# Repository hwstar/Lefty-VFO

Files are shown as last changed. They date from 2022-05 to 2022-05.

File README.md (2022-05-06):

# Lefty-VFO
Lefty Quad output VFO Motherboard

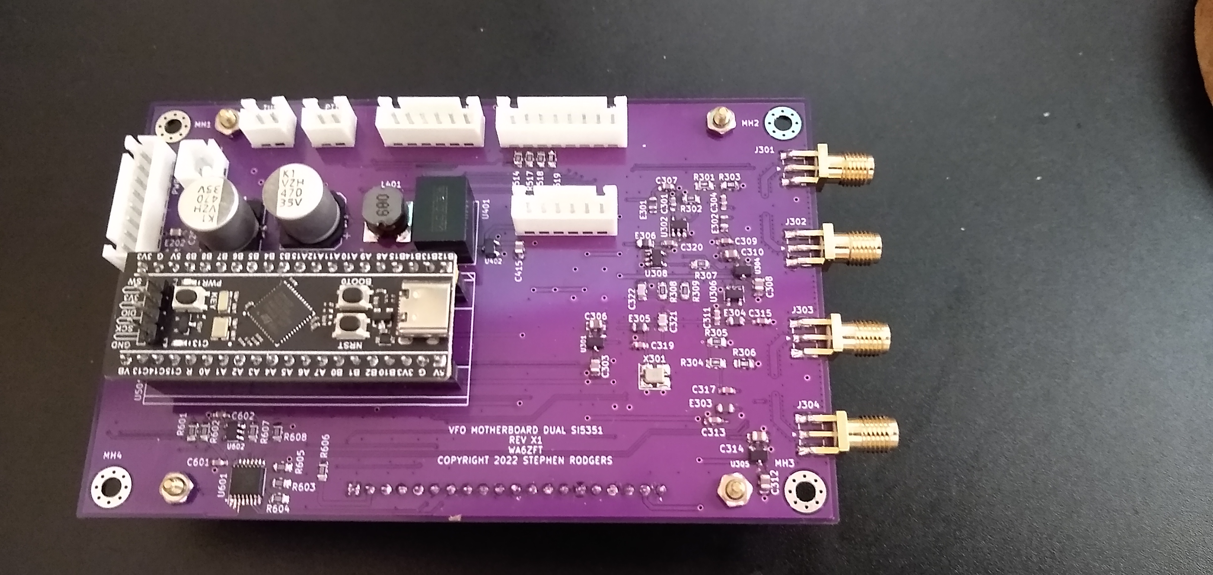
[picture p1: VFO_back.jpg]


This is a 4 output VFO module for the lefty transceiver.

It uses 2 SI5351/MS5351 clock generator chips. 

There is a 4 channel PCA9546 I2C multiplexer on the board which is used to switch between the two SI5351's since they have a fixed device address.

Each SI5351 is driven from a common 26 MHz TCXO source using 74LVC1G04's as a buffer.

The SI5351's have dedicated ME6211 3.3V regulators to reduce cross coupling of spurs on the 3.3v power rails.

The VFO board used a Weact "Black Pill" STM32 MPU module. This module has 512kB of flash and 128kB of ram.

The display mounts on the front of the board using a 20 pin female socket header. The display used is a 3.3V 12864 monochrome display with SPI bus capability.

The vfo board is powered from 9-15V and uses a 12V to 5V switching power supply module with input PI filter to reduce the noise generated from the switcher module.

There is one 8 pin JST XH connector supplies 12V power and provides access to the I2C bus coming from one of the PCA9546 outputs.

The vfo board supports an optional 4x4 keypad, and an optical encoder.

There are 2 pin connector for the fan output. 

There are 2 pin connectors for the ptt, tune, and s-meter inputs.

There is a 6 pin connector for the UART in the Black pill.

There is an I2C EEPROM on the board to facilitate storing VFO configuration settings

The PCB design was done with KiCAD 6.0. The BOM files are in .csv format and are included in the top level directory. There is a combined BOM, and separate top and bottom SMT BOM's.

The firmware for the VFO is in a separate project located [here] (https://github.com/hwstar/FW_VFO_STM32_BLACK_PILL_ST7920) 

The gerber files are in the directory VFO_Rev_X2_Gerbers.

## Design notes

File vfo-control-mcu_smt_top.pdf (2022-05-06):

vfo-control-mcu_smt_top

Page 1

Item Part Number Qty Reference(s) | Title/Description | Value on Schematic | Manufacturer | Manufacturer Part Number
1 800270-477 | 2 C201,C202 | CAP,ALUM,ELECT,GP,470UF,25V,SMD,CS=10MM | 470u | Open Market | N/A
2 800238-104 | 1 C206 | CAP,0805,0.1u,50V,X7R | 0.1u | Open Market | N/A
3 800000-104 | 12 C301,C304,C307,C309,C311,C313,C315,C317,C319,C320,C601,C602CAP,0603,0.1u,25V,X7R | 0.1u | Open Market | N/A
4 800238-105 | 6 C303,C306,C308,C310,C312,C314 | CAP,0805,1u,50V,X7R | 1u | Open Market | N/A
5 800238-103 | 2 C321,C322 | CAP,0805,0.01u,50V,X7R | 0.01u | Open Market | N/A
6 800003-106 | 1 C412 | CAP,0805,10u,25V,X5R | 10u | Open Market | N/A
7 800003-225 | 1 C415 | CAP,0805,2.2u,25V,X5R | 2.2u | Open Market | N/A
8 800040-600 | 7 E202,E301-E306 | FERRITE,CHIP,0603,600 OHM,500MA | FB0805 | TDK | MMZ1608S601A
9 800233-101 | 4 J301-J304 | CONN,SOC,SMA,LAUNCH,0.062 PCB | CONN_SMA_LAUNCH | Kinghelm | KH-SMA-KE8-G
10 800114-102 | 3 J402,J403,J405 | CONN,HDR,SHROUDED,2 CKT,5MM,XH SERIES | CONN2 | JST | B2B-XH-A
11 800114-108 | 2 J404,J506 | CONN,HDR,SHROUDED,8 CKT,5MM,XH SERIES | CONN8 | JST | B8B-XH-A
12 800114-106 | 2 J501,J502 | CONN,HDR,SHROUDED,6 CKT,5MM,XH SERIES | CONN6 | JST | B6B-XH-A
13 800281-101 | 1 L401 | IND,68UH,990MA,280MILLIOHM,SMD | 68uH | Recom | RLS-686
14 800235-680 | 2 R301,R304 | RES,0805,68,1% | | 68 Open Market | N/A
15 800235-101 | 4 R302,R303,R305,R306 | RES,0805,100,1% | | 100 Open Market | N/A
16 800235-300 | 1 R307 | RES,0805,30,1% | | 33 Open Market | N/A
17 800235-474 | 2 R308,R309 | RES,0805,470K,1% | 470K | Open Market | N/A
18 800235-330 | 4 R514,R517-R519 | RES,0805,33,1% | | 33 Open Market | N/A
19 800235-103 | 8 R601-R608 | RES,0805,10K,1% | 10K | Open Market | N/A
20 800187-101 | 4 U301,U304,U305,U402 | IC,VREG,LDO,500MA,3.3V,SOT23 | ME6211A33M3G-N | Nanjing Micro One Elec ME6211A33M3B-N
21 800289-101 | 3 U302,U306,U308 | IC,INVERTER,LVC04,SINGLE,SOT-23 | 74LVC1G04 | Texas Instruments | SN74LVC1G04DBVT
22 800201-500 | 1 U401 | MODULE,REGULATOR,SWITCHING,1A,5.0V | R-78E5.0-1.0 | Recom | R-78E5.0-1.0
23 800280-101 | 1 U501 | MODULE,STM32F411CEU6,BLACK PILL,40 PIN DIP | BLACK_PILL_WE_ACT_STM32F411CEU6 Open Market | N/A
24 800290-101 | 1 U601 | IC,SWITCH,I2C,4 CHANNEL,TSSOP16 | PCA9546APW | NEXPERIA | PCA9546APW,112
25 800284-101 | 1 U602 | IC,EEPROM,64KBIT,I2C,1.6-5.5V,SOT23-5 | 24CW640 | Microchip | 24CW640T-I/OT
26 800291-256 | 1 X301 | OSC,TCXO,26MHZ,0.5PPM,CLIPPED SINE, 3.3V,SMT,3225 OSC-ABRACON-ATX-11 | Abracon | ATX-11-F-26.000MHz-F05-T
27 XXXXXX-XXX | 0 | DNI | DNI | DNI | DNI

vfo-control-mcu_smt_top

Page 2

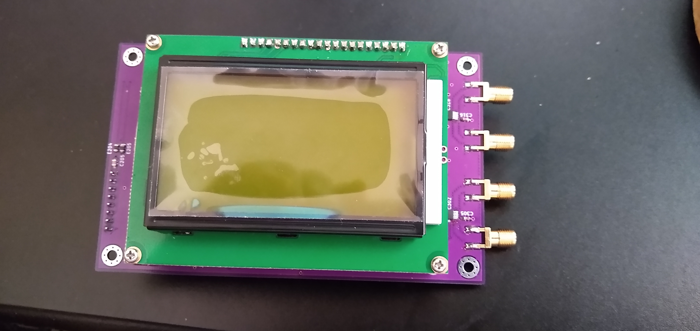
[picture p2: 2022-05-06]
VFO_front.jpg

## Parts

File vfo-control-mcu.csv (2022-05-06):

Item | Part Number | Qty | Reference(s) | Title/Description | Value on Schematic | Manufacturer | Manufacturer Part Number
1 | 800270-477 | 2 | C201,C203 | CAP,ALUM,ELECT,GP,470UF,25V,SMD,CS=10MM | 470u | Open Market | N/A
2 | 800239-102 | 2 | C202,C204 | CAP,0805,C0G/NPO,1000PF,50V | 1000p | Open Market | N/A
3 | 800238-104 | 7 | C205,C206,C405,C501-C504 | CAP,0805,0.1u,50V,X7R | 0.1u | Open Market | N/A
4 | 800063-104 | 16 | C301,C302,C304,C305,C307,C309,C311,C313,C315-C320,C601,C602 | CAP,0603,0.1u,50V,X7R | 0.1u | Open Market | N/A
5 | 800238-105 | 6 | C303,C306,C308,C310,C312,C314 | CAP,0805,1u,50V,X7R | 1u | Open Market | N/A
6 | 800238-103 | 2 | C321,C322 | CAP,0805,0.01u,50V,X7R | 0.01u | Open Market | N/A
7 | 800003-106 | 2 | C401,C402 | CAP,0805,10u,25V,X5R | 10u | Open Market | N/A
8 | 800003-225 | 2 | C403,C404 | CAP,0805,2.2u,25V,X5R | 2.2u | Open Market | N/A
9 | 800109-101 | 1 | CR201 | DIODE, RECT,SHOTTKY,1A,50V,SMA | S1A | Fairchild Semiconductor | ES1A
10 | 800245-601 | 11 | E201-E205,E301-E306 | FERRITE,CHIP,0805,600 ohm,100MHz,500mA | FB0805 | Sunlord | GZ2012U601TF
11 | 800283-020 | 1 | J201 | CONN,SOC,1X20,VERT,0.1 IN PITCH | Conn_01x20 | Open Market | N/A
12 | 800114-102 | 4 | J202-J204,J503 | CONN,HDR,SHROUDED,2 CKT,5MM,XH SERIES | CONN2 | JST | B2B-XH-A
13 | 800114-108 | 2 | J205,J501 | CONN,HDR,SHROUDED,8 CKT,5MM,XH SERIES | CONN8 | JST | B8B-XH-A
14 | 800233-101 | 4 | J301-J304 | CONN,SOC,SMA,LAUNCH,0.062 PCB | CONN_SMA_LAUNCH | Kinghelm | KH-SMA-KE8-G
15 | 800114-106 | 2 | J502,J504 | CONN,HDR,SHROUDED,6 CKT,5MM,XH SERIES | CONN6 | JST | B6B-XH-A
16 | 800281-101 | 1 | L401 | IND,68UH,990MA,280MILLIOHM,SMD | 68uH | Recom | RLS-686
17 | 800123-101 | 2 | Q201,Q202 | XSTR,MOSFET,N-CH,4.0A,30V,SOT-23 | SI2306 | Diodes Inc. | DMN3112S-7
17 |  |  |  |  |  | Vishay | SI2306BDS-T1-E3
18 | 800248-240 | 2 | R201,R202 | RES,2512,24 OHM, 1%,1W | 24 | Open Market | N/A
19 | 800235-680 | 2 | R301,R304 | RES,0805,68,1% | 68 | Open Market | N/A
20 | 800235-101 | 2 | R302,R305 | RES,0805,100,1% | 100 | Open Market | N/A
21 | 800235-330 | 8 | R303,R306,R307,R513,R516-R519 | RES,0805,33,1% | 33 | Open Market | N/A
22 | 800235-474 | 2 | R308,R309 | RES,0805,470K,1% | 470K | Open Market | N/A
23 | 800235-123 | 2 | R401,R522 | RES,0805,12K,1% | 12K | Open Market | N/A
24 | 800235-302 | 1 | R402 | RES,0805,3K,1% | 3K | Open Market | N/A
25 | 800235-332 | 10 | R501-R506,R523-R526 | RES,0805,3.3K,1% | 3.3K | Open Market | N/A
26 | 800235-221 | 4 | R507-R510 | RES,0805,220,1% | 220 | Open Market | N/A
27 | 800235-102 | 4 | R511,R512,R514,R515 | RES,0805,1.0K,1% | 1K | Open Market | N/A
28 | 800235-471 | 2 | R520,R521 | RES,0805,470,1% | 470 | Open Market | N/A
29 | 800235-103 | 8 | R601-R608 | RES,0805,10K,1% | 10K | Open Market | N/A
30 | 800187-101 | 4 | U301,U304,U305,U402 | IC,VREG,LDO,500MA,3.3V,SOT23 | ME6211A33M3G-N | Nanjing Micro One Elec | ME6211A33M3B-N
31 | 800289-101 | 3 | U302,U306,U308 | IC,INVERTER,LVC04,SINGLE,SOT-23 | 74LVC1G04 | Texas Instruments | SN74LVC1G04DBVT
32 | 800288-101 | 2 | U303,U307 | IC, PROG CLOCK GEN,3 OUTPUT, I2C,MSOP10 | Si5351 | RUIMENG TECHNOLOGY | MS5351M
32 |  |  |  |  |  | Skyworks | SI5351A-B-GTR
33 | 800201-500 | 1 | U401 | MODULE,REGULATOR,SWITCHING,1A,5.0V | R-78E5.0-1.0 | Recom | R-78E5.0-1.0
34 | 800280-101 | 1 | U501 | MODULE,STM32F411CEU6,BLACK PILL,40 PIN DIP | BLACK_PILL_WE_ACT_STM32F411CEU6 | Open Market | N/A
35 | 800199-101 | 2 | U502,U503 | IC,SCHMITT TRIGGER,INVERTING,2.0-5.5V,SOT23-5 | 74LVC1G14 | Texas Instruments | SN74LVC1G14DBVR
36 | 800290-101 | 1 | U601 | IC,SWITCH,I2C,4 CHANNEL,TSSOP16 | PCA9546APW | NEXPERIA | PCA9546APW,112
37 | 800284-101 | 1 | U602 | IC,EEPROM,64KBIT,I2C,1.6-5.5V,SOT23-5 | 24CW640 | Microchip | 24CW640T-I/OT
38 | 800291-256 | 1 | X301 | OSC,TCXO,26MHZ,0.5PPM,CLIPPED SINE, 3.3V,SMT,3225 | OSC-ABRACON-ATX-11 | Abracon | ATX-11-F-26.000MHz-F05-T
39 | XXXXXX-XXX | 0 |  | DNI | DNI | DNI | DNI

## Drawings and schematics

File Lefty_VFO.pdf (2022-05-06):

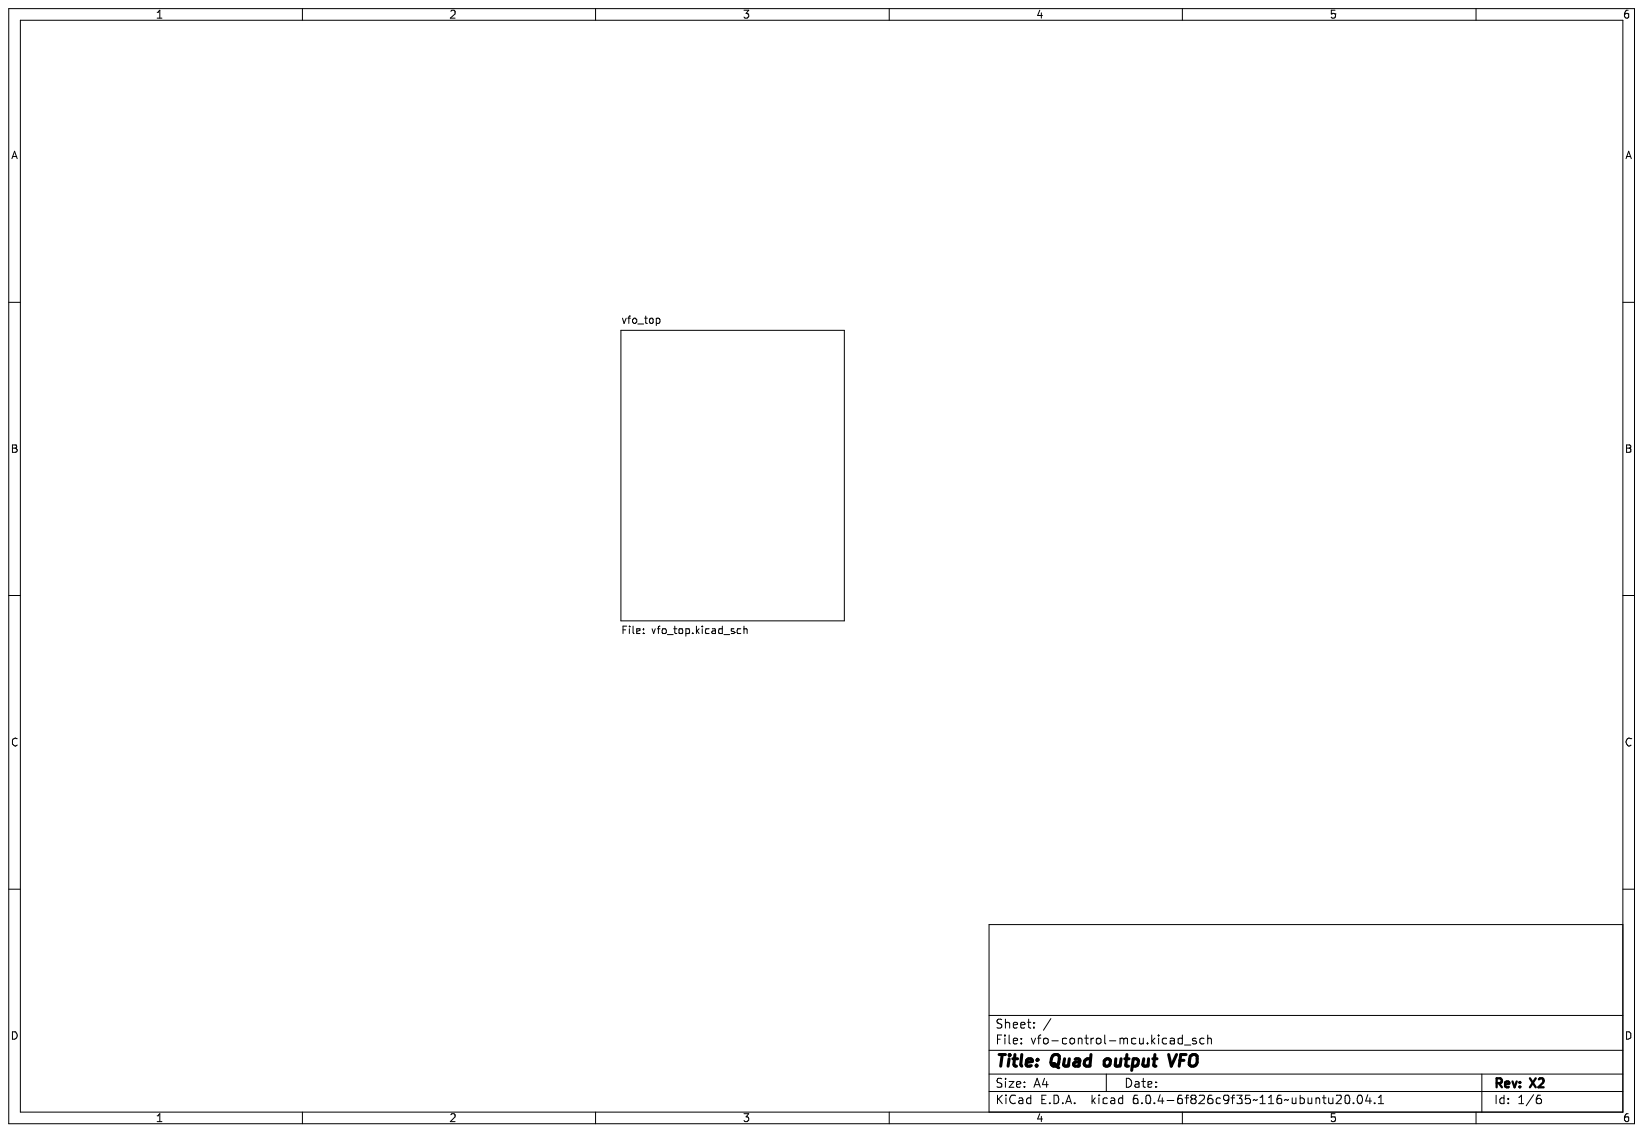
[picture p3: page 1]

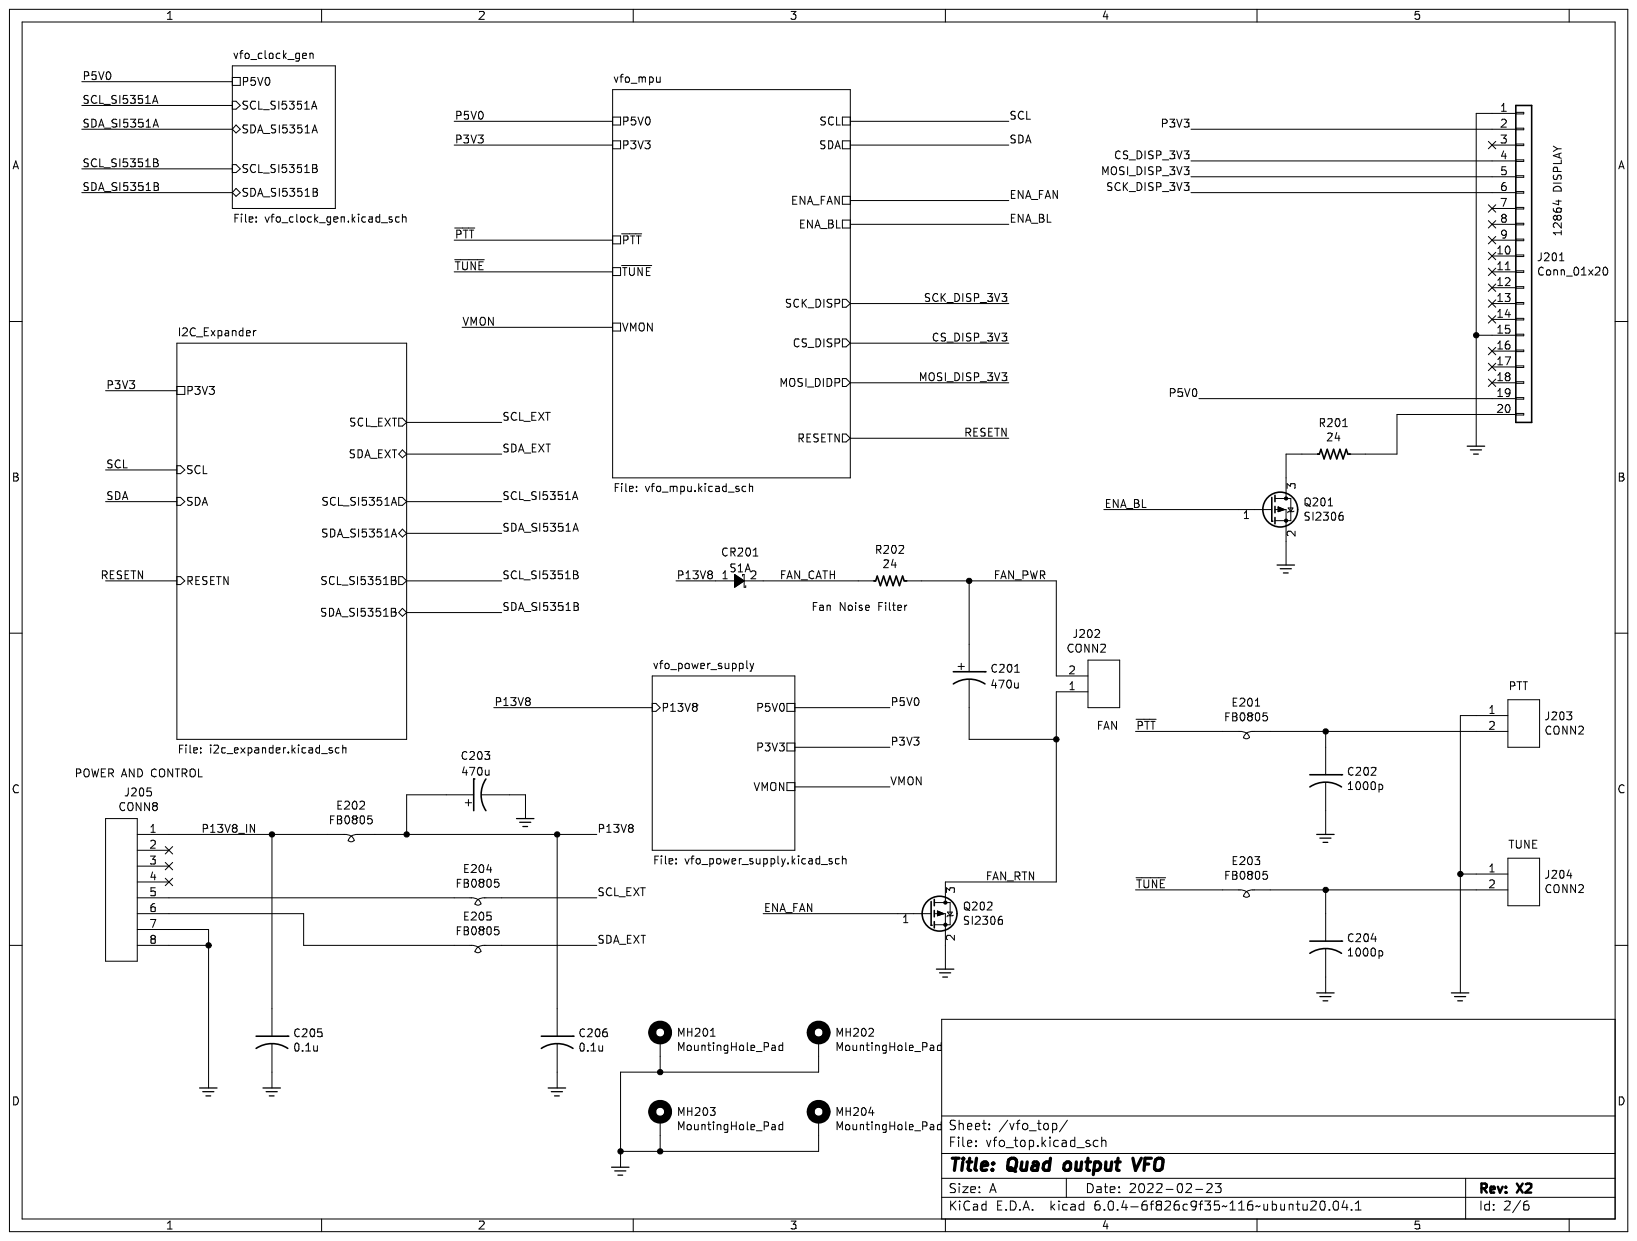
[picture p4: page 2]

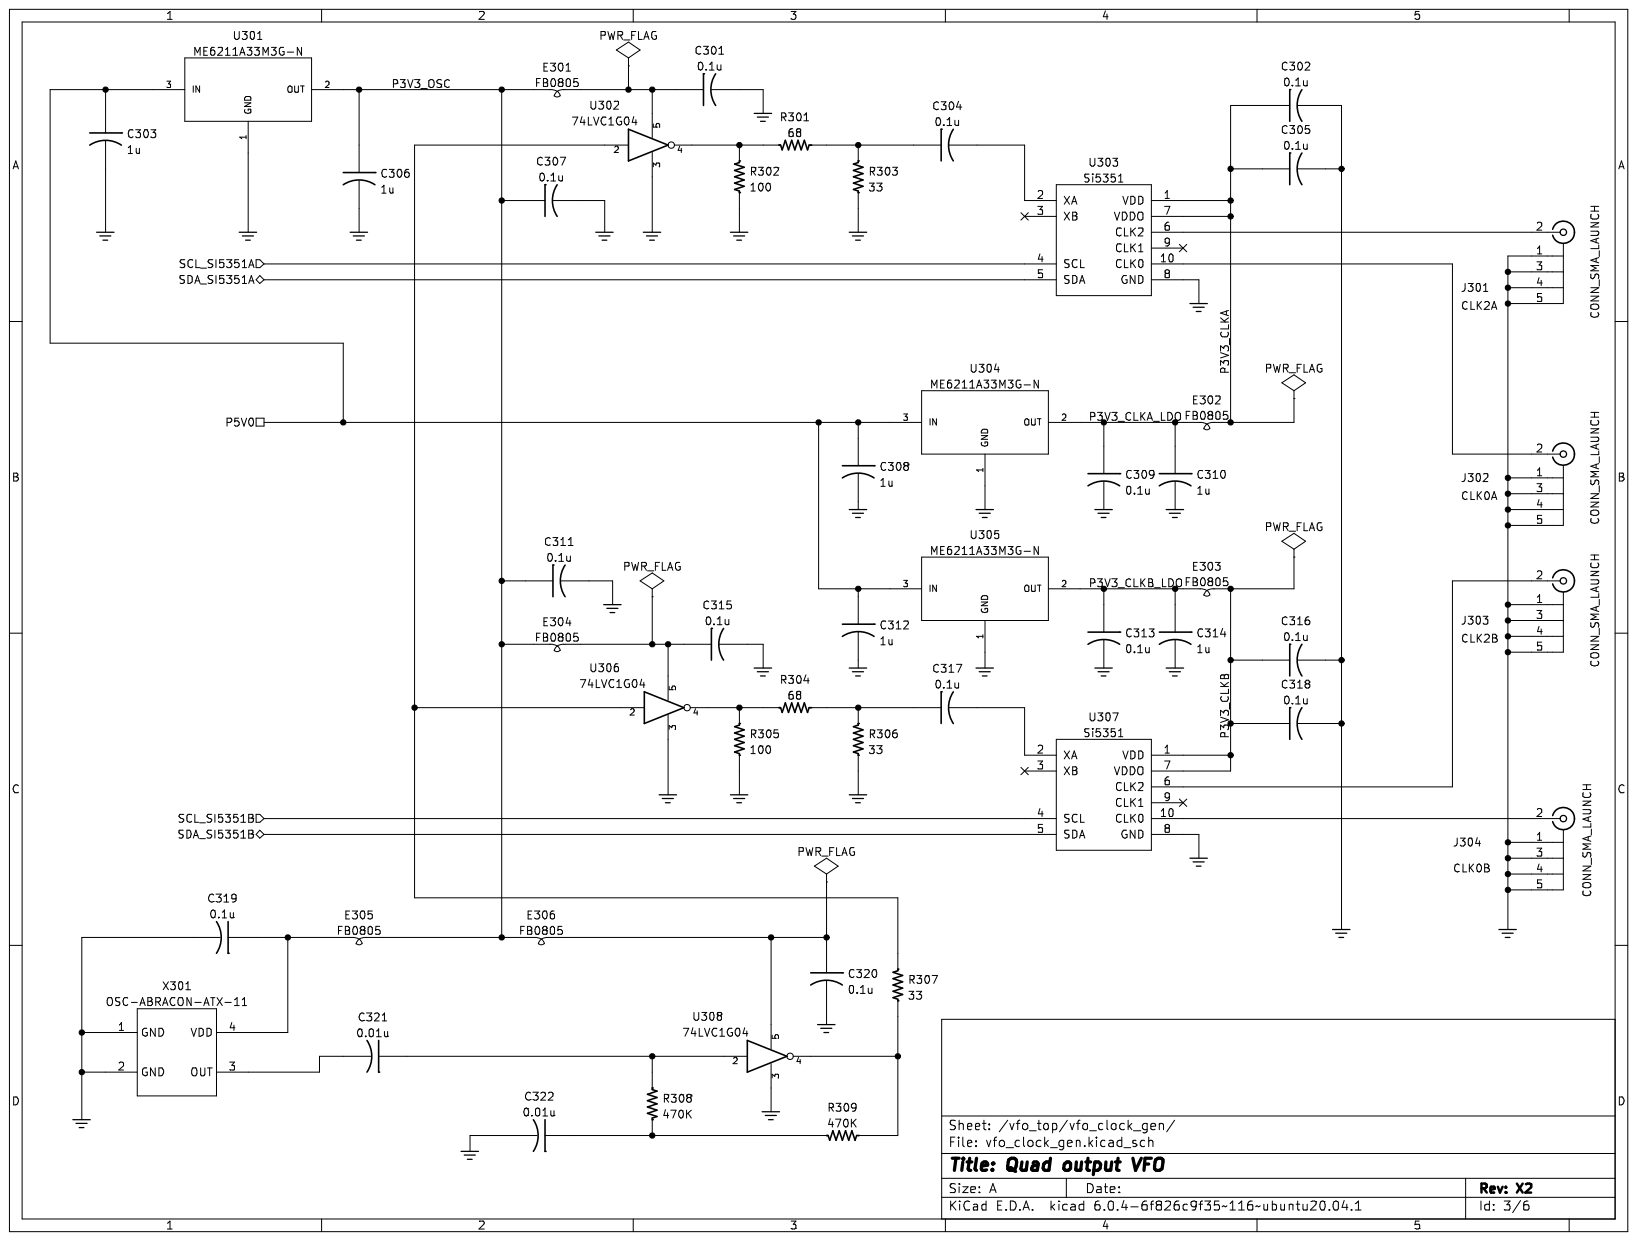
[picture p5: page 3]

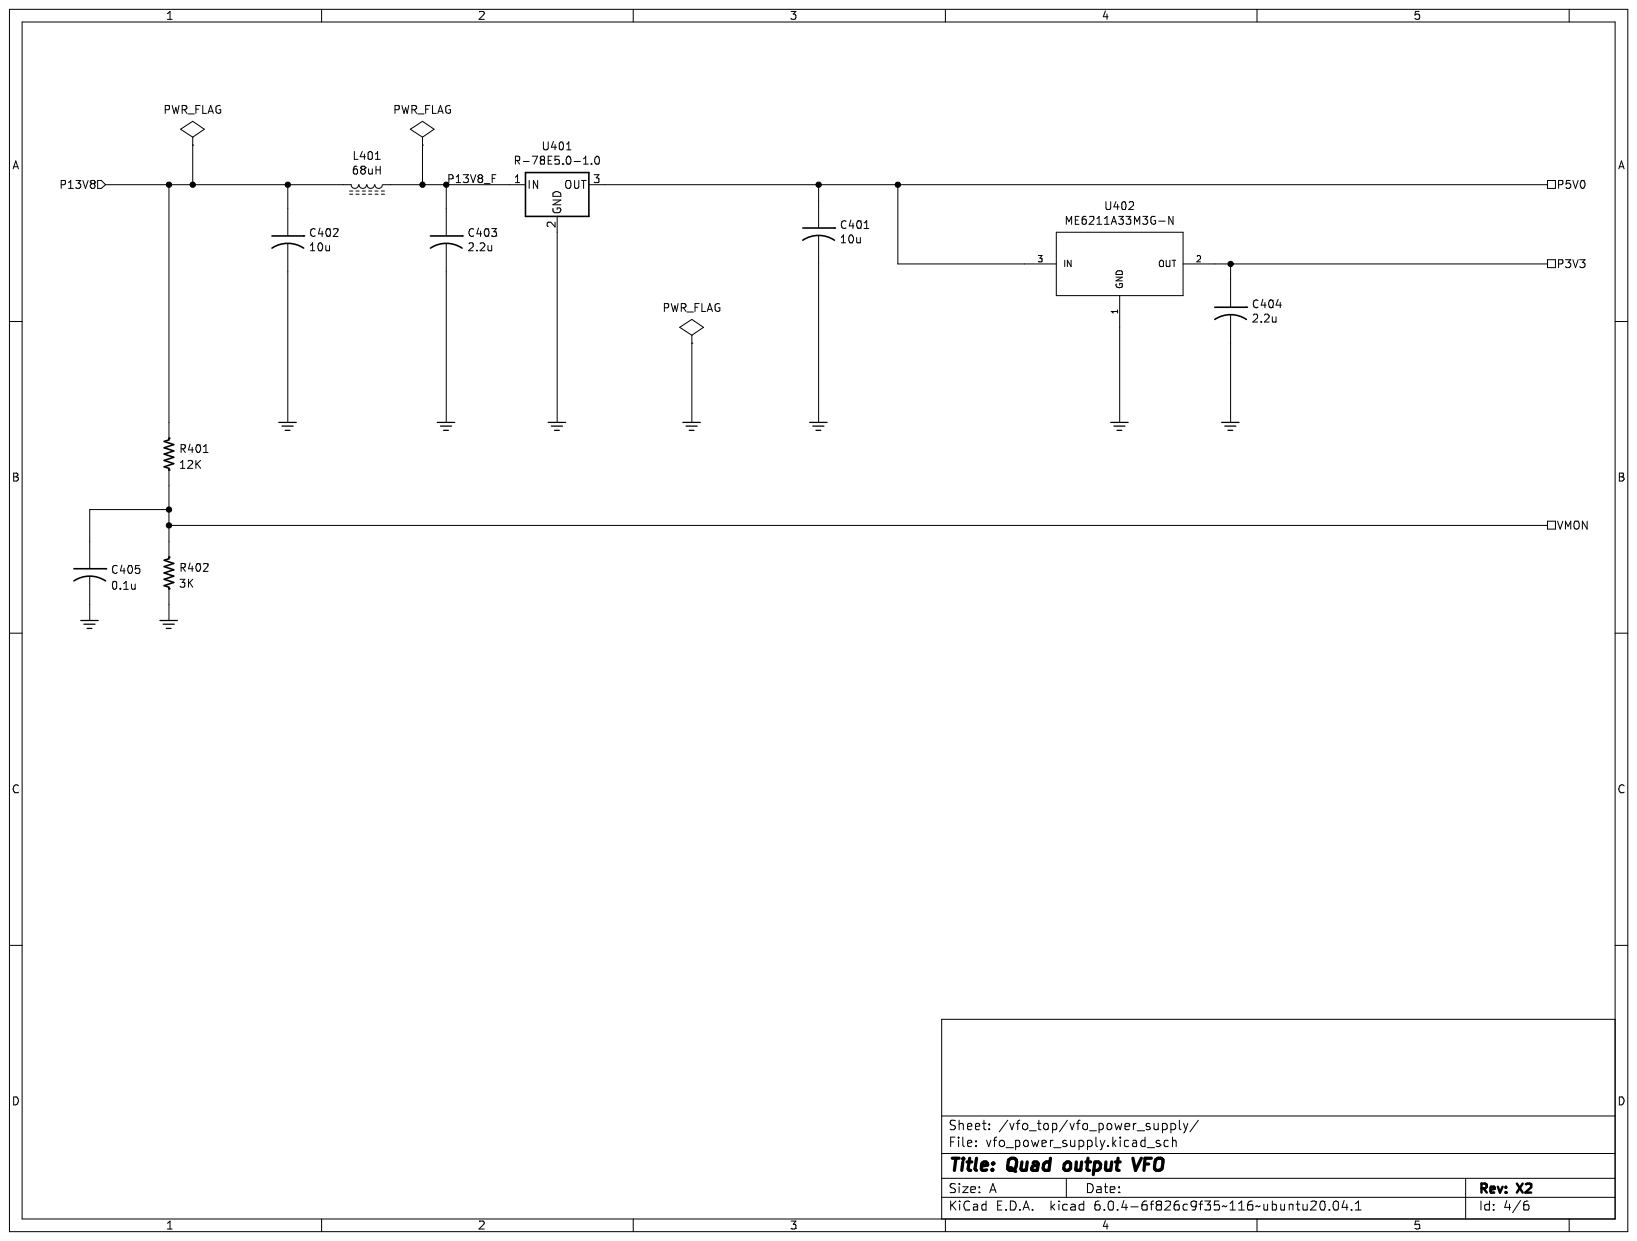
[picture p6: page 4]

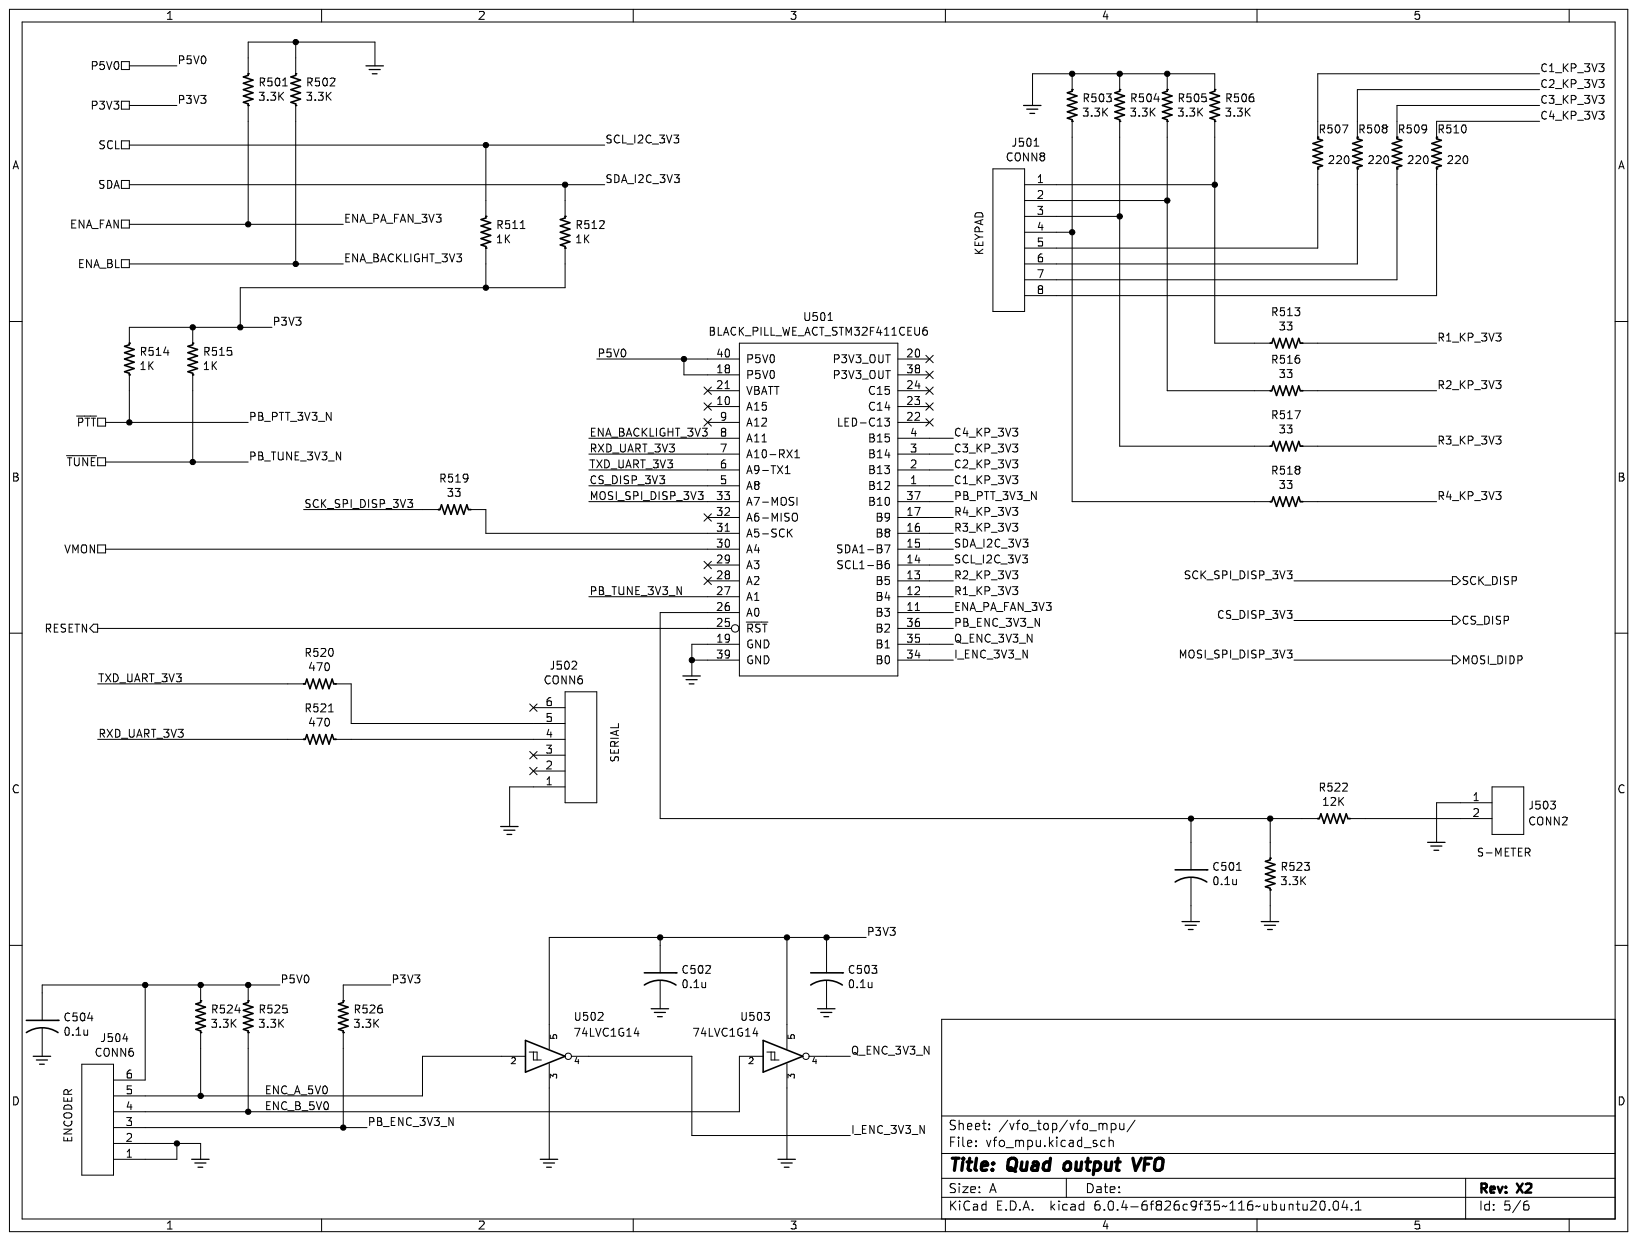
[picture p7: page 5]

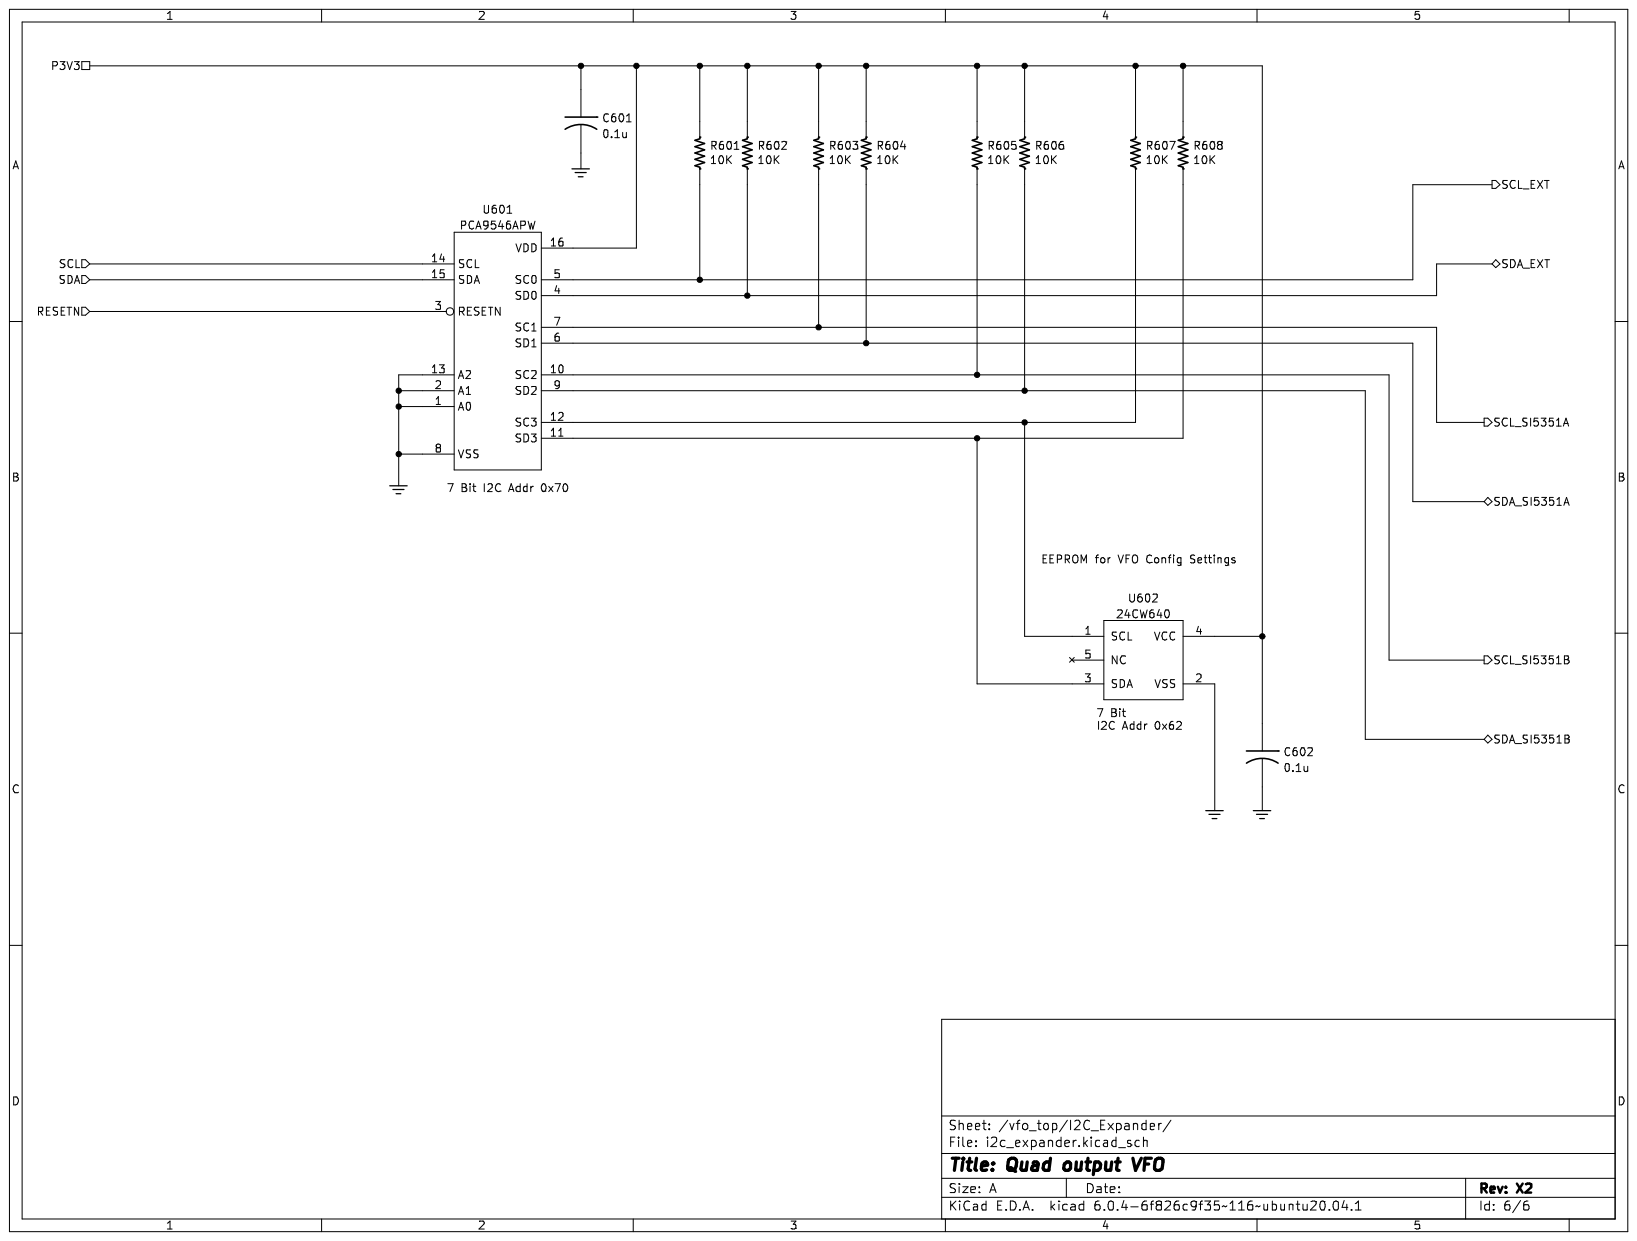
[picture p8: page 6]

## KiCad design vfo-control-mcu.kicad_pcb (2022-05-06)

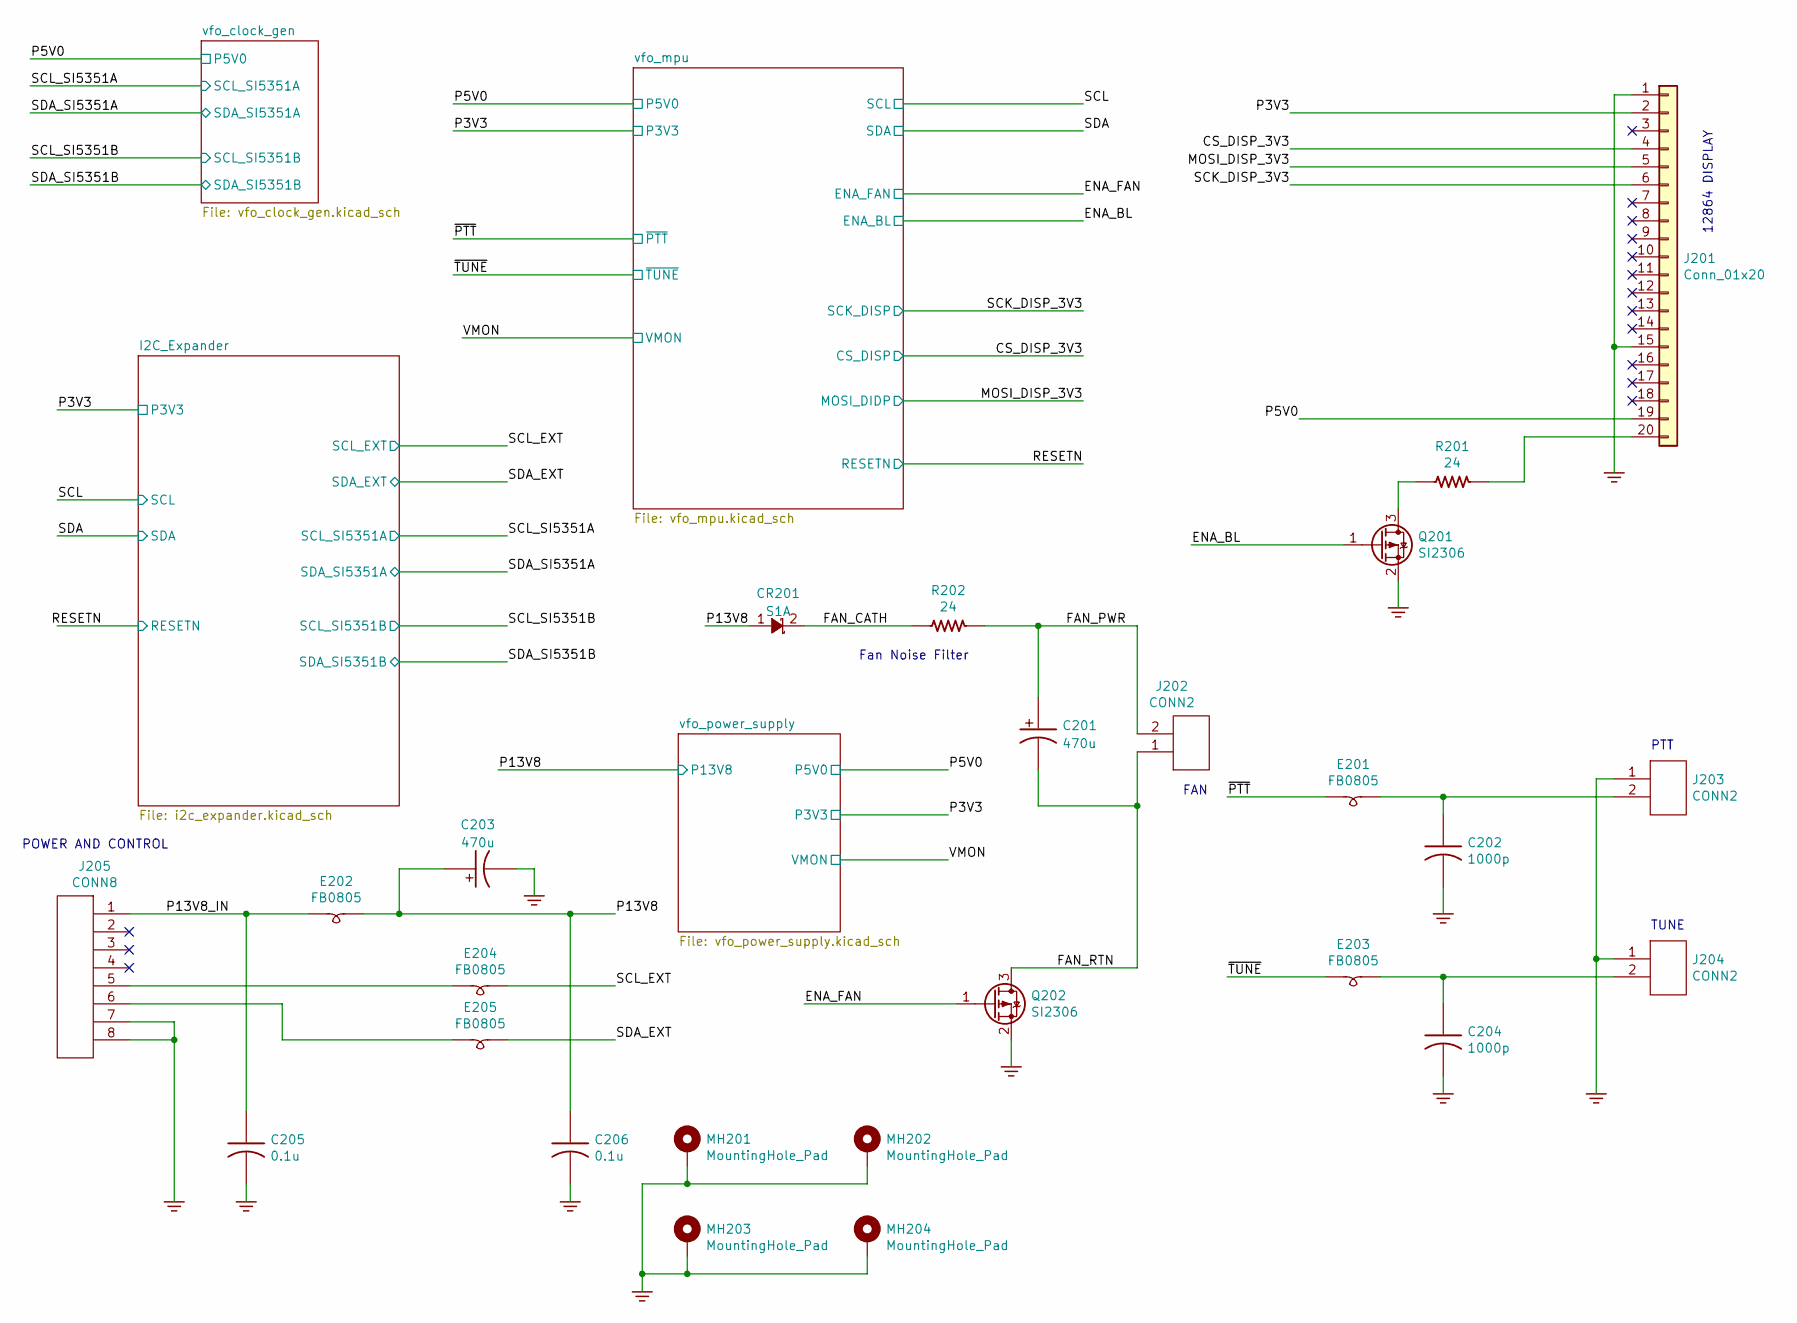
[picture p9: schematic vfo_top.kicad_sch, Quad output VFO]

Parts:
C201, C203: 470u; CP_Elec_10x10; PartNumber 800270-477
C202, C204: 1000p; C_0805_2012Metric_Pad1.18x1.45mm_HandSolder; PartNumber 800239-102
C205, C206: 0.1u; C_0805_2012Metric_Pad1.18x1.45mm_HandSolder; PartNumber 800238-104
CR201: S1A; SMA-SAR; PartNumber 800109-101
E201, E202, E203, E204, E205: FB0805; L_0805_2012Metric_Pad1.05x1.20mm_HandSolder; PartNumber 800245-601
J201: Conn_01x20; 12864_display; PartNumber 800283-020
J202, J203, J204: CONN2; JST_B2B_XH_A; PartNumber 800114-102
J205: CONN8; JST_B8B_XH_A; PartNumber 800114-108
MH201, MH202, MH203, MH204: MountingHole_Pad; MountingHole_3.2mm_M3_Pad_Via
Q201, Q202: SI2306; SOT-23; PartNumber 800123-101
R201, R202: 24; R_2512_6332Metric_Pad1.40x3.35mm_HandSolder; PartNumber 800248-240

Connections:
/vfo_top/CS_DISP_3V3: J201.4; also elsewhere on the board
/vfo_top/ENA_BL: Q201.1 (G); also elsewhere on the board
/vfo_top/ENA_FAN: Q202.1 (G); also elsewhere on the board
/vfo_top/FAN_CATH: CR201.2 (K), R202.2
/vfo_top/FAN_PWR: C201.1, J202.2, R202.1
/vfo_top/FAN_RTN: C201.2, J202.1, Q202.3 (D)
/vfo_top/MOSI_DISP_3V3: J201.5; also elsewhere on the board
/vfo_top/P3V3: J201.2; also elsewhere on the board
/vfo_top/P5V0: J201.19; also elsewhere on the board
/vfo_top/P13V8: C203.1, C206.1, CR201.1 (A), E202.2; also elsewhere on the board
/vfo_top/P13V8_IN: C205.1, E202.1, J205.1
/vfo_top/SCK_DISP_3V3: J201.6; also elsewhere on the board
/vfo_top/SCL_EXT: E204.2; also elsewhere on the board
/vfo_top/SDA_EXT: E205.2; also elsewhere on the board
/vfo_top/~PTT: E201.1; also elsewhere on the board
/vfo_top/~TUNE: E203.1; also elsewhere on the board
GND: C202.2, C203.2, C204.2, C205.2, C206.2, J201.1, J201.15, J203.1, J204.1, J205.7, J205.8, MH201.1, MH202.1, MH203.1, MH204.1, Q201.2 (S), Q202.2 (S); also elsewhere on the board
unnamed: C202.1, E201.2, J203.2
unnamed: C204.1, E203.2, J204.2
unnamed: E204.1, J205.5
unnamed: E205.1, J205.6
unnamed: J201.20, R201.1
unnamed: Q201.3 (D), R201.2

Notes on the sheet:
POWER AND CONTROL
PTT
TUNE
12864 DISPLAY
Fan Noise Filter
FAN

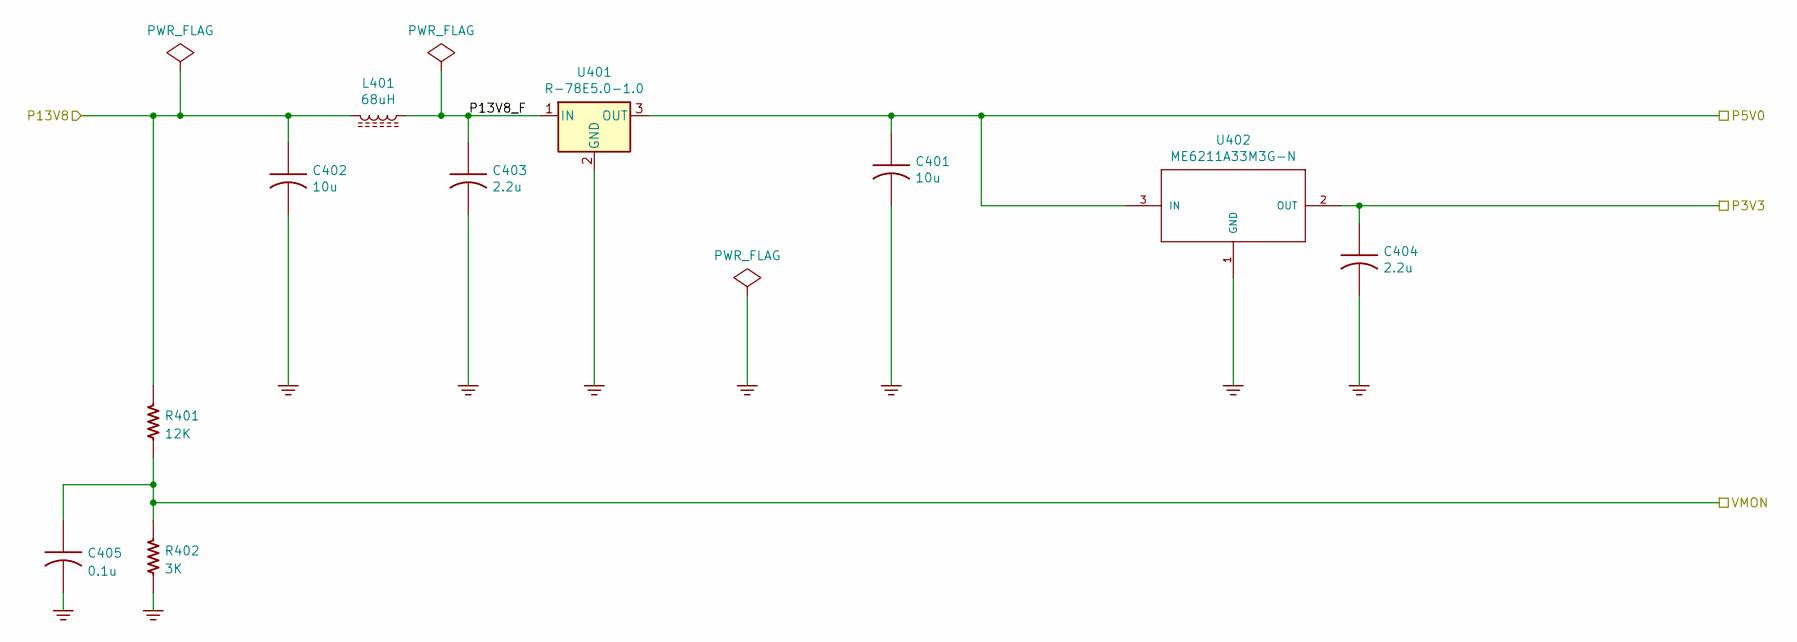
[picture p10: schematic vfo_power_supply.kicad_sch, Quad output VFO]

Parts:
C401, C402: 10u; C_0805_2012Metric_Pad1.18x1.45mm_HandSolder; PartNumber 800003-106
C403, C404: 2.2u; C_0805_2012Metric_Pad1.18x1.45mm_HandSolder; PartNumber 800003-225
C405: 0.1u; C_0805_2012Metric_Pad1.18x1.45mm_HandSolder; PartNumber 800238-104
L401: 68uH; IND-DRUM-7.8MMx5MM; PartNumber 800281-101
R401: 12K; R_0805_2012Metric_Pad1.20x1.40mm_HandSolder; PartNumber 800235-123
R402: 3K; R_0805_2012Metric_Pad1.20x1.40mm_HandSolder; PartNumber 800235-302
U401: R-78E5.0-1.0; RECom_R-78Ex.x-1.0; PartNumber 800201-500
U402: ME6211A33M3G-N; SOT23-3-SAR-V2; PartNumber 800187-101

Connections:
/vfo_top/P3V3: C404.1, U402.2 (OUT); also elsewhere on the board
/vfo_top/P5V0: C401.1, U401.3 (OUT), U402.3 (IN); also elsewhere on the board
/vfo_top/P13V8: C402.1, L401.2, R401.1; also elsewhere on the board
/vfo_top/VMON: C405.1, R401.2, R402.1; also elsewhere on the board
/vfo_top/vfo_power_supply/P13V8_F: C403.1, L401.1, U401.1 (IN)
GND: C401.2, C402.2, C403.2, C404.2, C405.2, R402.2, U401.2 (GND), U402.1 (GND); also elsewhere on the board

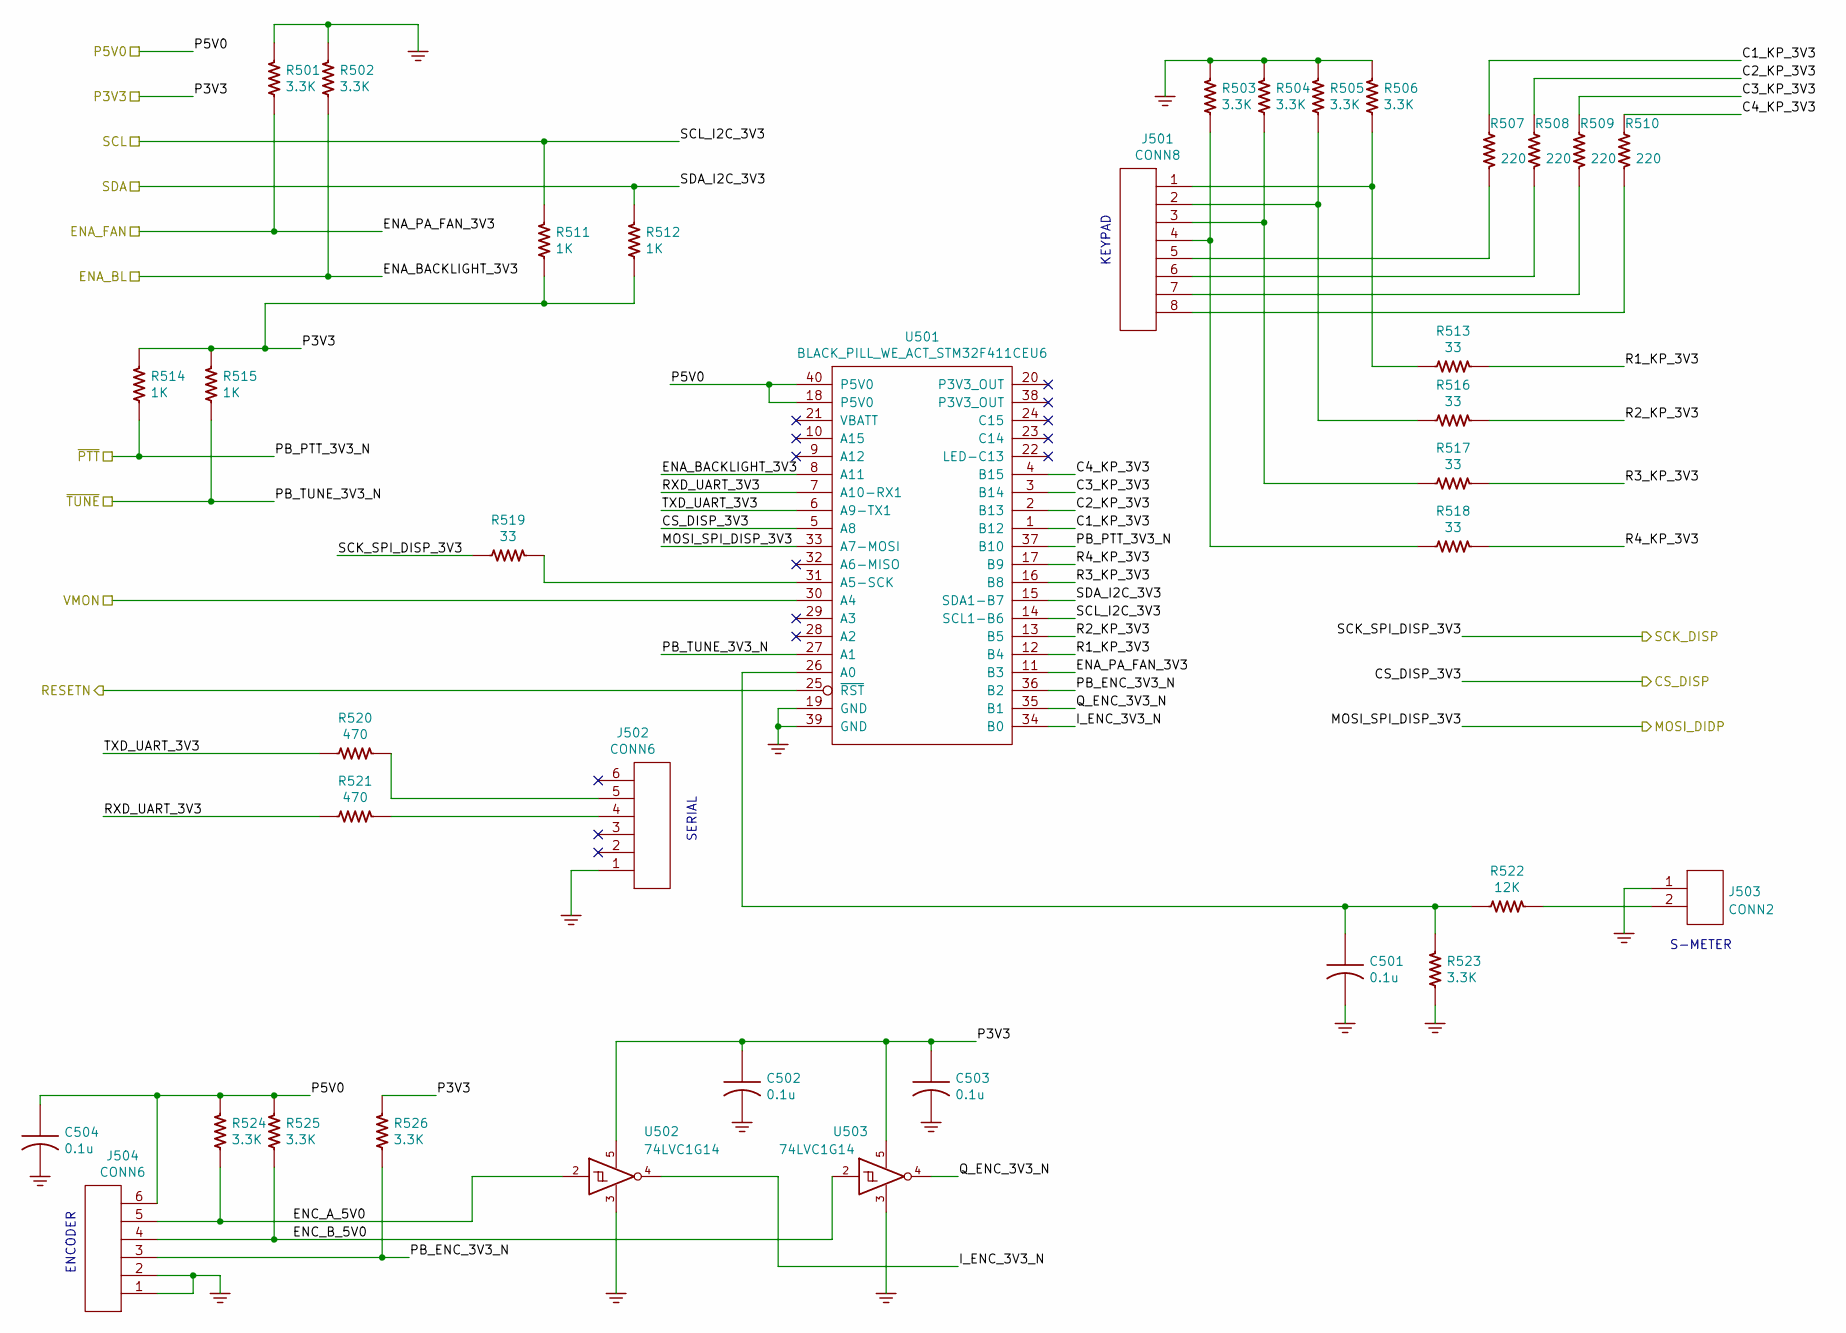
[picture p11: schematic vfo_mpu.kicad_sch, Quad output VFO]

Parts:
C501, C502, C503, C504: 0.1u; C_0805_2012Metric_Pad1.18x1.45mm_HandSolder; PartNumber 800238-104
J501: CONN8; JST_B8B_XH_A; PartNumber 800114-108
J502, J504: CONN6; JST_B6B_XH_A; PartNumber 800114-106
J503: CONN2; JST_B2B_XH_A; PartNumber 800114-102
R501, R502, R503, R504, R505, R506, R523, R524, R525, R526: 3.3K; R_0805_2012Metric_Pad1.20x1.40mm_HandSolder; PartNumber 800235-332
R507, R508, R509, R510: 220; R_0805_2012Metric_Pad1.20x1.40mm_HandSolder; PartNumber 800235-221
R511, R512, R514, R515: 1K; R_0805_2012Metric_Pad1.20x1.40mm_HandSolder; PartNumber 800235-102
R513, R516, R517, R518, R519: 33; R_0805_2012Metric_Pad1.20x1.40mm_HandSolder; PartNumber 800235-330
R520, R521: 470; R_0805_2012Metric_Pad1.20x1.40mm_HandSolder; PartNumber 800235-471
R522: 12K; R_0805_2012Metric_Pad1.20x1.40mm_HandSolder; PartNumber 800235-123
U501: BLACK_PILL_WE_ACT_STM32F411CEU6; BLACK_PILL_WE_ACT_STM32F411; PartNumber 800280-101
U502, U503: 74LVC1G14; SOT-23-5; PartNumber 800199-101

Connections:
/vfo_top/CS_DISP_3V3: U501.5 (A8); also elsewhere on the board
/vfo_top/ENA_BL: R502.2, U501.8 (A11); also elsewhere on the board
/vfo_top/ENA_FAN: R501.2, U501.11 (B3); also elsewhere on the board
/vfo_top/MOSI_DISP_3V3: U501.33 (A7-MOSI); also elsewhere on the board
/vfo_top/P3V3: C502.1, C503.1, R511.2, R512.2, R514.1, R515.1, R526.1, U502.5 (VCC), U503.5 (VCC); also elsewhere on the board
/vfo_top/P5V0: C504.1, J504.6, R524.1, R525.1, U501.18 (P5V0), U501.40 (P5V0); also elsewhere on the board
/vfo_top/RESETN: U501.25 (~RST); also elsewhere on the board
/vfo_top/SCK_DISP_3V3: R519.2; also elsewhere on the board
/vfo_top/SCL: R511.1, U501.14 (SCL1-B6); also elsewhere on the board
/vfo_top/SDA: R512.1, U501.15 (SDA1-B7); also elsewhere on the board
/vfo_top/VMON: U501.30 (A4); also elsewhere on the board
/vfo_top/vfo_mpu/C1_KP_3V3: R507.2, U501.1 (B12)
/vfo_top/vfo_mpu/C2_KP_3V3: R508.2, U501.2 (B13)
/vfo_top/vfo_mpu/C3_KP_3V3: R509.2, U501.3 (B14)
/vfo_top/vfo_mpu/C4_KP_3V3: R510.2, U501.4 (B15)
/vfo_top/vfo_mpu/ENC_A_5V0: J504.5, R524.2, U502.2
/vfo_top/vfo_mpu/ENC_B_5V0: J504.4, R525.2, U503.2
/vfo_top/vfo_mpu/I_ENC_3V3_N: U501.34 (B0), U502.4
/vfo_top/vfo_mpu/PB_ENC_3V3_N: J504.3, R526.2, U501.36 (B2)
/vfo_top/vfo_mpu/Q_ENC_3V3_N: U501.35 (B1), U503.4
/vfo_top/vfo_mpu/R1_KP_3V3: R513.1, U501.12 (B4)
/vfo_top/vfo_mpu/R2_KP_3V3: R516.1, U501.13 (B5)
/vfo_top/vfo_mpu/R3_KP_3V3: R517.1, U501.16 (B8)
/vfo_top/vfo_mpu/R4_KP_3V3: R518.1, U501.17 (B9)
/vfo_top/vfo_mpu/RXD_UART_3V3: R521.2, U501.7 (A10-RX1)
/vfo_top/vfo_mpu/TXD_UART_3V3: R520.2, U501.6 (A9-TX1)
/vfo_top/~PTT: R514.2, U501.37 (B10); also elsewhere on the board
/vfo_top/~TUNE: R515.2, U501.27 (A1); also elsewhere on the board
GND: C501.2, C502.2, C503.2, C504.2, J502.1, J503.1, J504.1, J504.2, R501.1, R502.1, R503.1, R504.1, R505.1, R506.1, R523.2, U501.19 (GND), U501.39 (GND), U502.3 (GND), U503.3 (GND); also elsewhere on the board
unnamed: C501.1, R522.2, R523.1, U501.26 (A0)
unnamed: J501.1, R506.2, R513.2
unnamed: J501.2, R505.2, R516.2
unnamed: J501.3, R504.2, R517.2
unnamed: J501.4, R503.2, R518.2
unnamed: J501.5, R507.1
unnamed: J501.6, R508.1
unnamed: J501.7, R509.1
unnamed: J501.8, R510.1
unnamed: J502.4, R521.1
unnamed: J502.5, R520.1
unnamed: J503.2, R522.1
unnamed: R519.1, U501.31 (A5-SCK)

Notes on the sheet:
KEYPAD
ENCODER
SERIAL
S-METER

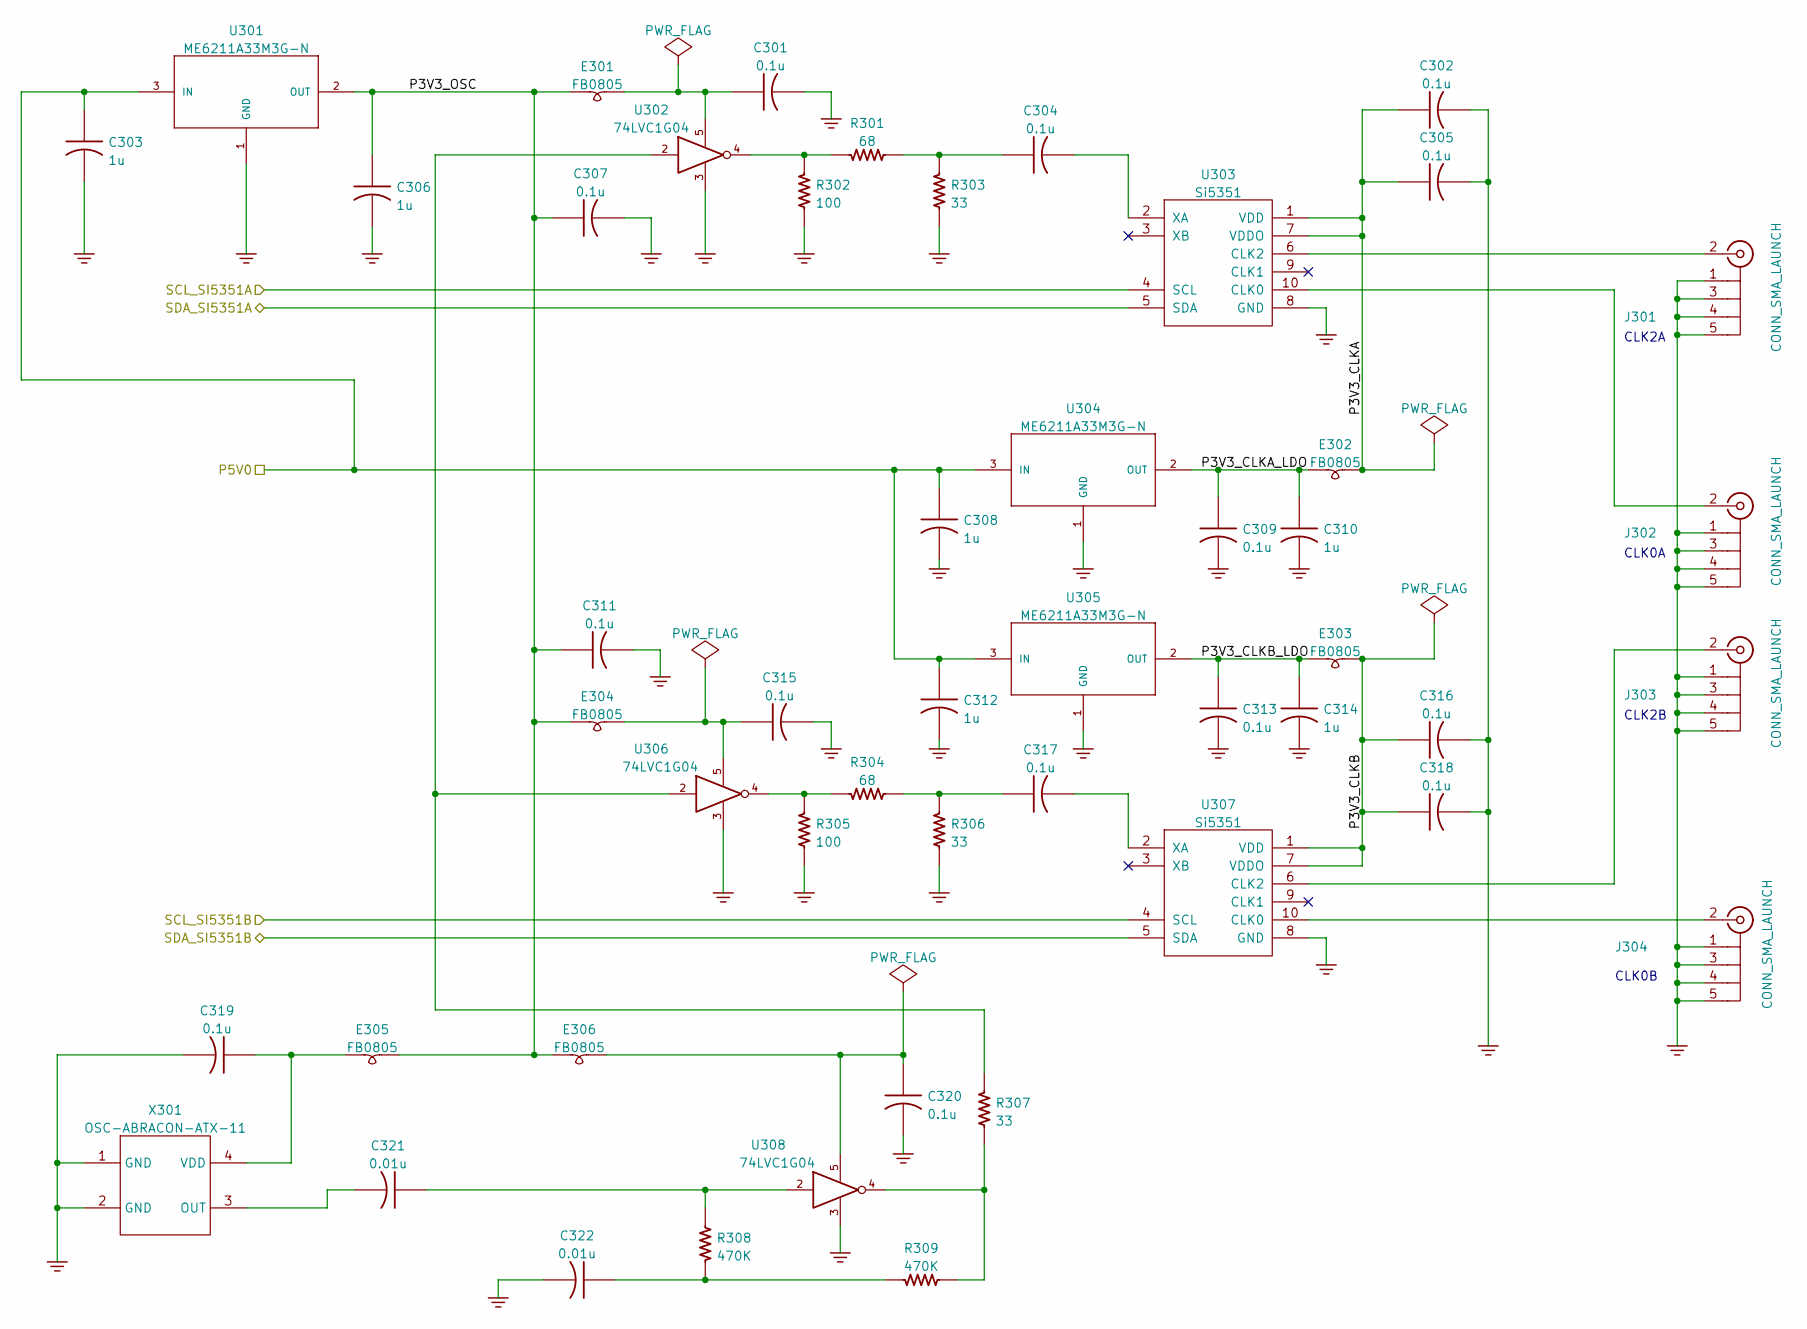
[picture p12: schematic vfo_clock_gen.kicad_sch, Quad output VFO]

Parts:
C301, C302, C304, C305, C307, C309, C311, C313, C315, C316, C317, C318, C319, C320: 0.1u; C_0603_1608Metric_Pad1.08x0.95mm_HandSolder; PartNumber 800063-104
C303, C306, C308, C310, C312, C314: 1u; C_0805_2012Metric_Pad1.18x1.45mm_HandSolder; PartNumber 800238-105
C321, C322: 0.01u; C_0805_2012Metric_Pad1.18x1.45mm_HandSolder; PartNumber 800238-103
E301, E302, E303, E304, E305, E306: FB0805; L_0805_2012Metric_Pad1.05x1.20mm_HandSolder; PartNumber 800245-601
J301, J302, J303, J304: CONN_SMA_LAUNCH; SMA_Launch_Kinghelm_KH-SMA-KE8-G; PartNumber 800233-101
R301, R304: 68; R_0805_2012Metric_Pad1.20x1.40mm_HandSolder; PartNumber 800235-680
R302, R305: 100; R_0805_2012Metric_Pad1.20x1.40mm_HandSolder; PartNumber 800235-101
R303, R306, R307: 33; R_0805_2012Metric_Pad1.20x1.40mm_HandSolder; PartNumber 800235-330
R308, R309: 470K; R_0805_2012Metric_Pad1.20x1.40mm_HandSolder; PartNumber 800235-474
U301, U304, U305: ME6211A33M3G-N; SOT23-3-SAR-V2; PartNumber 800187-101
U302, U306, U308: 74LVC1G04; SOT-23-5; PartNumber 800289-101
U303, U307: Si5351; MSOP-10-SAR; PartNumber 800288-101
X301: OSC-ABRACON-ATX-11; Oscillator_SMD_Abracon_ASE-4Pin_3.2x2.5mm_HandSoldering; PartNumber 800291-256

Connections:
/vfo_top/P5V0: C303.1, C308.1, C312.1, U301.3 (IN), U304.3 (IN), U305.3 (IN); also elsewhere on the board
/vfo_top/SCL_SI5351A: U303.4 (SCL); also elsewhere on the board
/vfo_top/SCL_SI5351B: U307.4 (SCL); also elsewhere on the board
/vfo_top/SDA_SI5351A: U303.5 (SDA); also elsewhere on the board
/vfo_top/SDA_SI5351B: U307.5 (SDA); also elsewhere on the board
/vfo_top/vfo_clock_gen/P3V3_CLKA: C302.1, C305.1, E302.2, U303.1 (VDD), U303.7 (VDDO)
/vfo_top/vfo_clock_gen/P3V3_CLKA_LDO: C309.1, C310.1, E302.1, U304.2 (OUT)
/vfo_top/vfo_clock_gen/P3V3_CLKB: C316.1, C318.1, E303.2, U307.1 (VDD), U307.7 (VDDO)
/vfo_top/vfo_clock_gen/P3V3_CLKB_LDO: C313.1, C314.1, E303.1, U305.2 (OUT)
/vfo_top/vfo_clock_gen/P3V3_OSC: C306.1, C307.1, C311.1, E301.1, E304.1, E305.2, E306.1, U301.2 (OUT)
GND: C301.2, C302.2, C303.2, C305.2, C306.2, C307.2, C308.2, C309.2, C310.2, C311.2, C312.2, C313.2, C314.2, C315.2, C316.2, C318.2, C319.2, C320.2, C322.2, J301.1, J301.3, J301.4, J301.5, J302.1, J302.3, J302.4, J302.5, J303.1, J303.3, J303.4, J303.5, J304.1, J304.3, J304.4, J304.5, R302.2, R303.2, R305.2, R306.2, U301.1 (GND), U302.3 (GND), U303.8 (GND), U304.1 (GND), U305.1 (GND), U306.3 (GND), U307.8 (GND), U308.3 (GND), X301.1 (GND), X301.2 (GND); also elsewhere on the board
unnamed: C301.1, E301.2, U302.5 (VCC)
unnamed: C304.1, R301.2, R303.1
unnamed: C304.2, U303.2 (XA)
unnamed: C315.1, E304.2, U306.5 (VCC)
unnamed: C317.1, R304.2, R306.1
unnamed: C317.2, U307.2 (XA)
unnamed: C319.1, E305.1, X301.4 (VDD)
unnamed: C320.1, E306.2, U308.5 (VCC)
unnamed: C321.1, R308.2, U308.2
unnamed: C321.2, X301.3 (OUT)
unnamed: C322.1, R308.1, R309.1
unnamed: J301.2, U303.6 (CLK2)
unnamed: J302.2, U303.10 (CLK0)
unnamed: J303.2, U307.6 (CLK2)
unnamed: J304.2, U307.10 (CLK0)
unnamed: R301.1, R302.1, U302.4
unnamed: R304.1, R305.1, U306.4
unnamed: R307.1, U302.2, U306.2
unnamed: R307.2, R309.2, U308.4

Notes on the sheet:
CLK0B
CLK0A
CLK2A
CLK2B

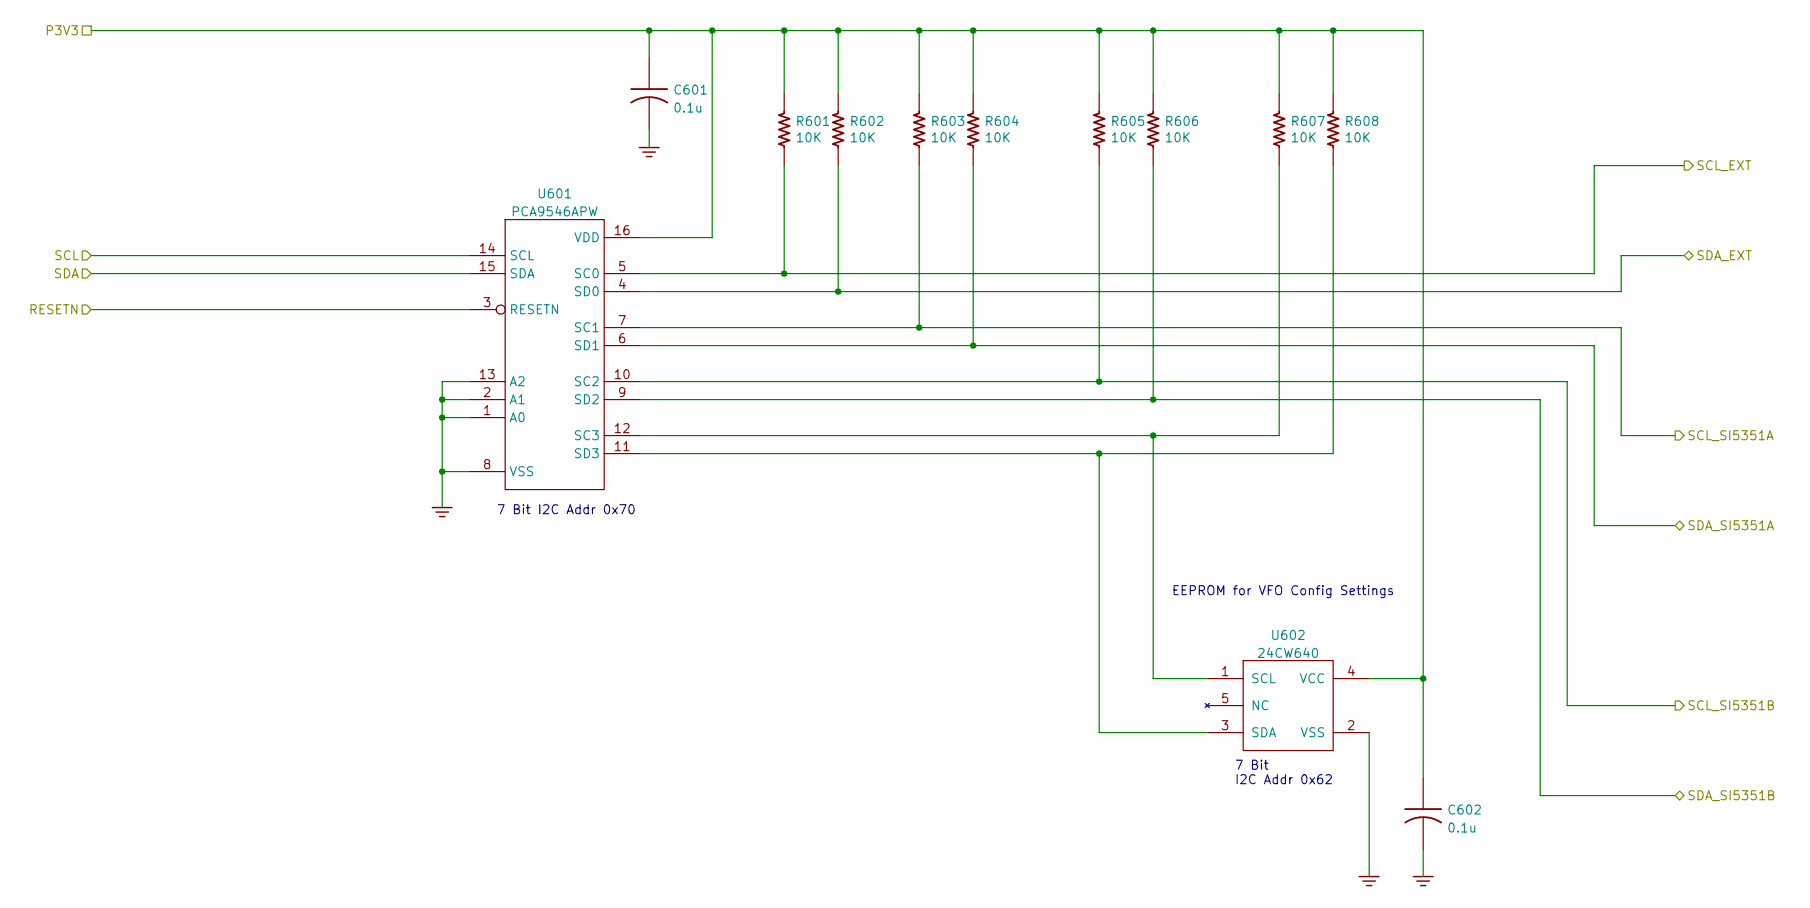
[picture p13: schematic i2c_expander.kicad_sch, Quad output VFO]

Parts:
C601, C602: 0.1u; C_0603_1608Metric_Pad1.08x0.95mm_HandSolder; PartNumber 800063-104
R601, R602, R603, R604, R605, R606, R607, R608: 10K; R_0805_2012Metric_Pad1.20x1.40mm_HandSolder; PartNumber 800235-103
U601: PCA9546APW; TSSOP-16_4.4x5mm_P0.65mm; PartNumber 800290-101
U602: 24CW640; SOT23-5-SAR; PartNumber 800284-101

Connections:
/vfo_top/P3V3: C601.1, C602.1, R601.1, R602.1, R603.1, R604.1, R605.1, R606.1, R607.1, R608.1, U601.16 (VDD), U602.4 (VCC); also elsewhere on the board
/vfo_top/RESETN: U601.3 (RESETN); also elsewhere on the board
/vfo_top/SCL: U601.14 (SCL); also elsewhere on the board
/vfo_top/SCL_EXT: R601.2, U601.5 (SC0); also elsewhere on the board
/vfo_top/SCL_SI5351A: R603.2, U601.7 (SC1); also elsewhere on the board
/vfo_top/SCL_SI5351B: R605.2, U601.10 (SC2); also elsewhere on the board
/vfo_top/SDA: U601.15 (SDA); also elsewhere on the board
/vfo_top/SDA_EXT: R602.2, U601.4 (SD0); also elsewhere on the board
/vfo_top/SDA_SI5351A: R604.2, U601.6 (SD1); also elsewhere on the board
/vfo_top/SDA_SI5351B: R606.2, U601.9 (SD2); also elsewhere on the board
GND: C601.2, C602.2, U601.1 (A0), U601.2 (A1), U601.8 (VSS), U601.13 (A2), U602.2 (VSS); also elsewhere on the board
unnamed: R607.2, U601.12 (SC3), U602.1 (SCL)
unnamed: R608.2, U601.11 (SD3), U602.3 (SDA)

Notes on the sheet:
EEPROM for VFO Config Settings
7 Bit I2C Addr 0x62
7 Bit I2C Addr 0x70

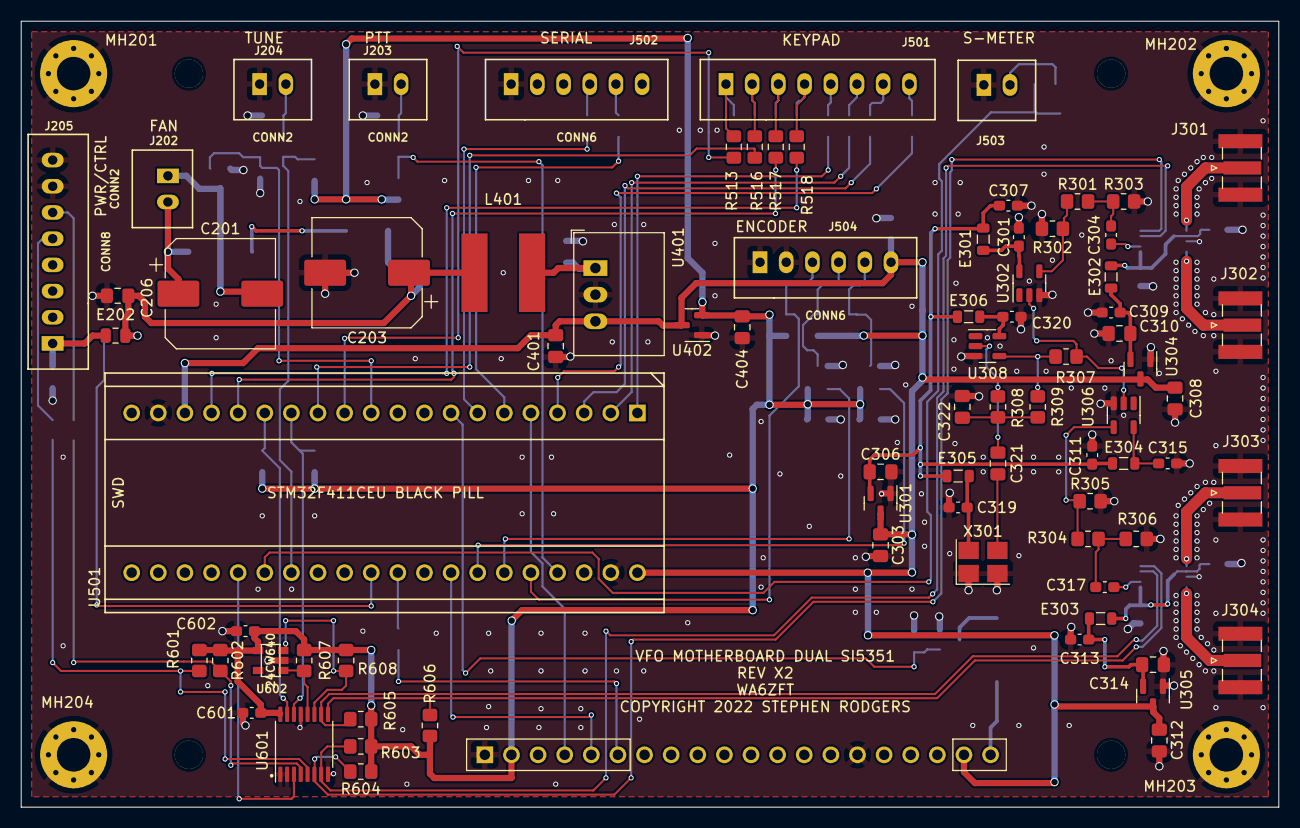
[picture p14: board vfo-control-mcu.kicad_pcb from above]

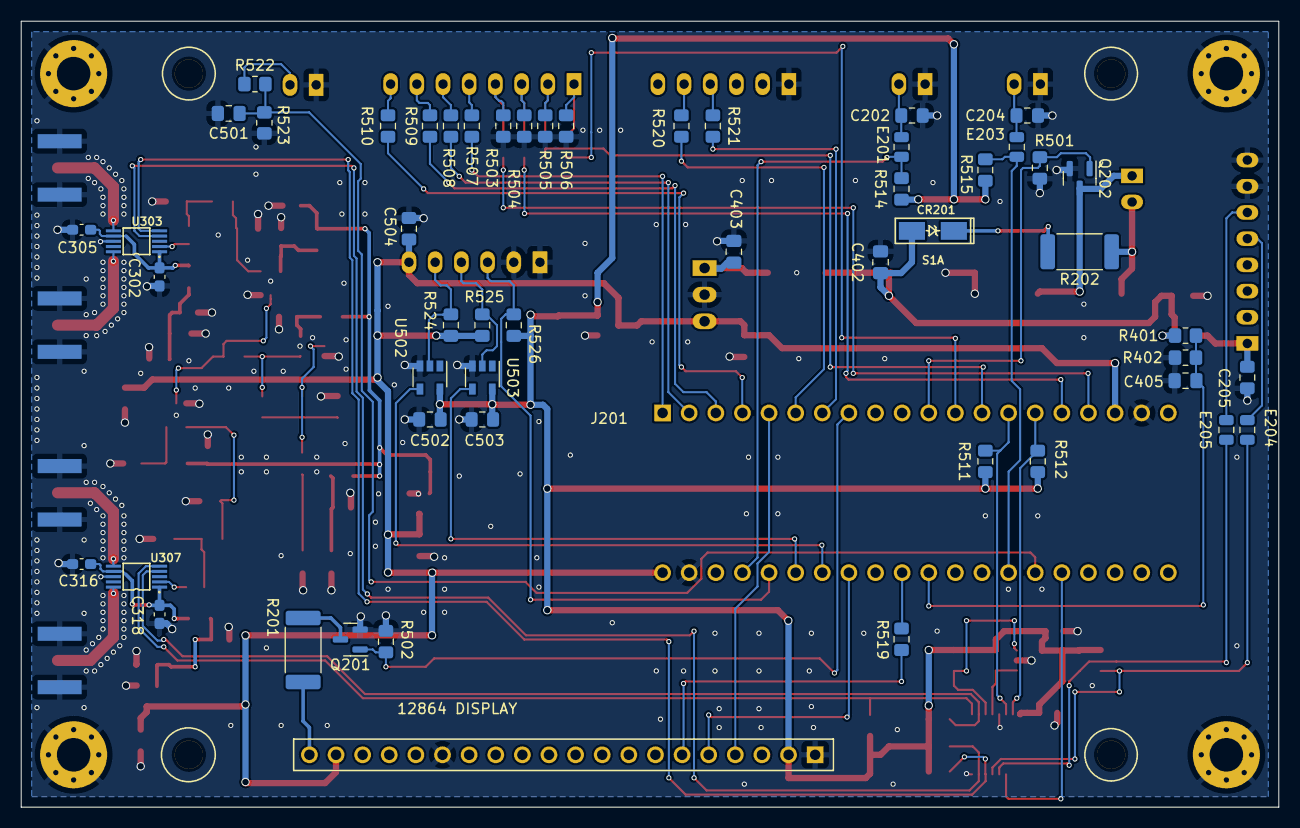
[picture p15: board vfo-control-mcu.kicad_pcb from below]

Board: 2 copper layers, 120.0 x 75.0 mm, 134 parts (52 on the bottom side), 86 nets.

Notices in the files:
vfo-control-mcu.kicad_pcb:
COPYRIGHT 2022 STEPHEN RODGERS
